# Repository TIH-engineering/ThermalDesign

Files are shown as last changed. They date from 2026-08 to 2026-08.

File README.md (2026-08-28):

# ThermalDesign






## 🔌 Leiterplattenbeschreibung

Die Leiterplatte **ThermalDesign** dient zur praktischen Untersuchung des **thermischen Verhaltens elektronischer Bauteile**. Als Versuchsobjekt werden mehrere LM317-Linearregler unter unterschiedlichen thermischen Bedingungen und bei verschiedenen Belastungen betrieben.

Die Leiterplatte enthält vier vergleichbare Spannungsreglerstufen mit einer Ausgangsspannung von etwa **2,5 V**. Die Regler unterscheiden sich insbesondere hinsichtlich ihrer thermischen Anbindung:

- **LM317 im SOT-223-Gehäuse**
- **LM317 im TO-220-Gehäuse**
- **LM317 im SOT-223-Gehäuse mit zusätzlicher Kupferfläche zur Wärmeabfuhr**
- **LM317 im TO-220-Gehäuse mit Kühlkörper**

Über verschiedene Lastwiderstände können unterschiedliche Lastfälle eingestellt werden. Vorgesehen sind Untersuchungen bei ungefähr:

- **100 mA**
- **250 mA**
- **500 mA**
- **1 A** als gepulste Last

Die 1-A-Last wird über einen MOSFET geschaltet und kann mit einem externen PWM-Signal angesteuert werden. Dadurch lassen sich neben stationären Temperaturzuständen auch **dynamische Erwärmungs- und Abkühlvorgänge** untersuchen.

Mit der Leiterplatte können unter anderem der Zusammenhang zwischen **Verlustleistung, Bauteiltemperatur, thermischem Widerstand, Gehäusebauform, Kupferfläche und Kühlkörper** experimentell untersucht werden. Die Messergebnisse können mit theoretischen Berechnungen oder thermischen Ersatzschaltbildern verglichen werden.

> **Einsatzgebiet:** Laborübungen und Unterricht zu thermischem Design, Verlustleistung, Wärmewiderständen, Linearreglern und Kühlung elektronischer Bauteile

---

## 📥 Downloads

| Datei | Beschreibung |
|---|---|
| 📄 [Schaltplan (PDF)](../../releases/latest/download/schematic.pdf) | Schaltplan der Leiterplatte |
| 🖨️ [Leiterplatte (PDF)](../../releases/latest/download/pcb.pdf) | Leiterplattenansicht als PDF |
| 🔩 [Bohrplan (PDF)](../../releases/latest/download/drill.pdf) | Bohrdaten / Bohrplan |
| 📋 [Stückliste (Excel)](../../releases/latest/download/bom.xlsx) | Bill of Materials |
| 🌐 [Interactive BOM](../../releases/latest/download/ibom.html) | Interaktive Bestückungsansicht |
| 📦 [Fertigungsdaten](../../releases/latest/download/kicad.zip) | Gerber- und Bohrdaten |
| 🧊 [STEP-Modell](../../releases/latest/download/pcb.step) | 3D-Modell der Leiterplatte |

Die Dateien werden automatisch durch den Release-Workflow erzeugt.

---

## 🖥️ Leiterplatte

### Vorschau

| Oberseite | Unterseite |
|:---:|:---:|
| PCB Top | PCB Bottom |

### Oberseite

PCB Top

### Unterseite

PCB Bottom

---

## ℹ️ Projektinformationen

| Eigenschaft | Wert |
|---|---|
| **Projekt** | ThermalDesign |
| **Software** | KiCad 10 |
| **Repository** | TIH-engineering/ThermalDesign |
| **Autor** | [TIH] |
| **Lizenz** | CC BY-NC-SA 4.0 |

---

## 🗂️ Repository-Struktur

```text
.
├── .github/
│   └── workflows/       # GitHub Actions
├── .kibot/              # KiBot-Konfiguration
├── pcb/
│   ├── lib/             # Projektspezifische Bibliotheken
│   └── ...              # KiCad-Projektdateien
├── .gitignore
├── LICENSE
└── README.md

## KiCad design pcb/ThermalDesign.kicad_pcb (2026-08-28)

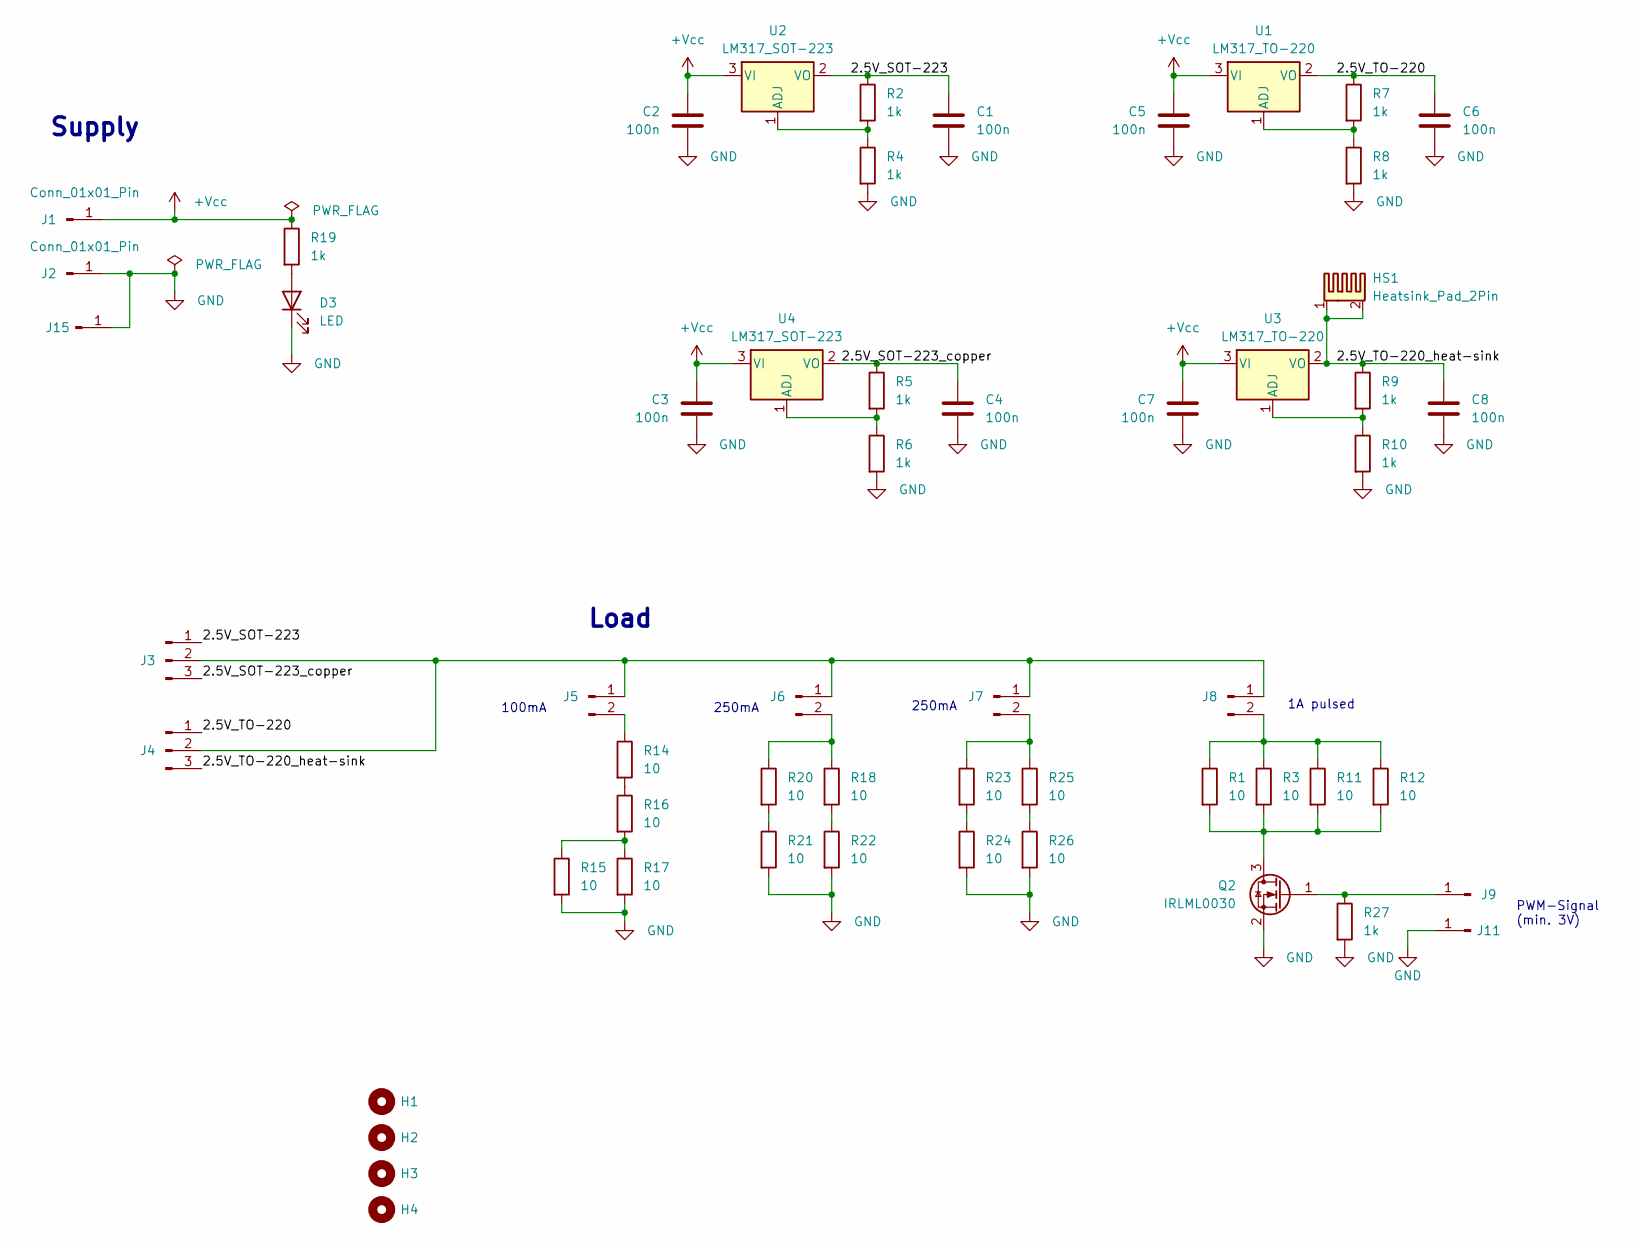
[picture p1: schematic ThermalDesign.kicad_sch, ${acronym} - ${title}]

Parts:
C1, C2, C3, C4, C5, C6, C7, C8: 100n; C_1206_3216Metric
D3: LED; LED_1206_3216Metric
H1, H2, H3, H4: MountingHole; MountingHole_3.2mm_M3
HS1: Heatsink_Pad_2Pin; Heatsink_Fischer_SK129-STS_42x25mm_2xDrill2.5mm
J1, J2, J9, J11, J15: Conn_01x01_Pin; PinHeader_1x01_P2.54mm_Vertical
J3, J4: Conn_01x03_Pin; PinHeader_1x03_P2.54mm_Vertical
J5, J6, J7, J8: Conn_01x02_Pin; PinHeader_1x02_P2.54mm_Vertical
Q2: IRLML0030; SOT-23
R1, R3, R11, R12, R14, R15, R16, R17, R18, R20, R21, R22, R23, R24, R25, R26: 10; R_1206_3216Metric
R2, R4, R5, R6, R7, R8, R9, R10, R19, R27: 1k; R_1206_3216Metric
U1, U3: LM317_TO-220; TO-220-3_Vertical
U2, U4: LM317_SOT-223; SOT-223-3_TabPin2

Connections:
+Vcc: C2.1, C3.1, C5.1, C7.1, J1.1 (Pin_1_1), R19.1, U1.3 (VI), U2.3 (VI), U3.3 (VI), U4.3 (VI)
/2.5V_SOT-223: C1.1, J3.1, R2.1, U2.2 (VO)
/2.5V_SOT-223_copper: C4.1, J3.3, R5.1, U4.2 (VO)
/2.5V_TO-220: C6.1, J4.1, R7.1, U1.2 (VO)
/2.5V_TO-220_heat-sink: C8.1, HS1.1, HS1.2, J4.3, R9.1, U3.2 (VO)
GND: C1.2, C2.2, C3.2, C4.2, C5.2, C6.2, C7.2, C8.2, D3.1 (K), J2.1 (Pin_1_1), J11.1 (Pin_1_1), J15.1 (Pin_1_1), Q2.2 (S), R4.2, R6.2, R8.2, R10.2, R15.2, R17.2, R21.2, R22.2, R24.2, R26.2, R27.2
unnamed: D3.2 (A), R19.2
unnamed: J3.2, J4.2, J5.1, J6.1, J7.1, J8.1
unnamed: J5.2, R14.1
unnamed: J6.2, R18.1, R20.1
unnamed: J7.2, R23.1, R25.1
unnamed: J8.2, R1.1, R3.1, R11.1, R12.1
unnamed: J9.1 (Pin_1_1), Q2.1 (G), R27.1
unnamed: Q2.3 (D), R1.2, R3.2, R11.2, R12.2
unnamed: R14.2, R16.1
unnamed: R15.1, R16.2, R17.1
unnamed: R18.2, R22.1
unnamed: R20.2, R21.1
unnamed: R23.2, R24.1
unnamed: R25.2, R26.1
unnamed: R7.2, R8.1, U1.1 (ADJ)
unnamed: R2.2, R4.1, U2.1 (ADJ)
unnamed: R9.2, R10.1, U3.1 (ADJ)
unnamed: R5.2, R6.1, U4.1 (ADJ)

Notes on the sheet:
250mA
PWM-Signal (min. 3V)
Supply
100mA
Load
1A pulsed

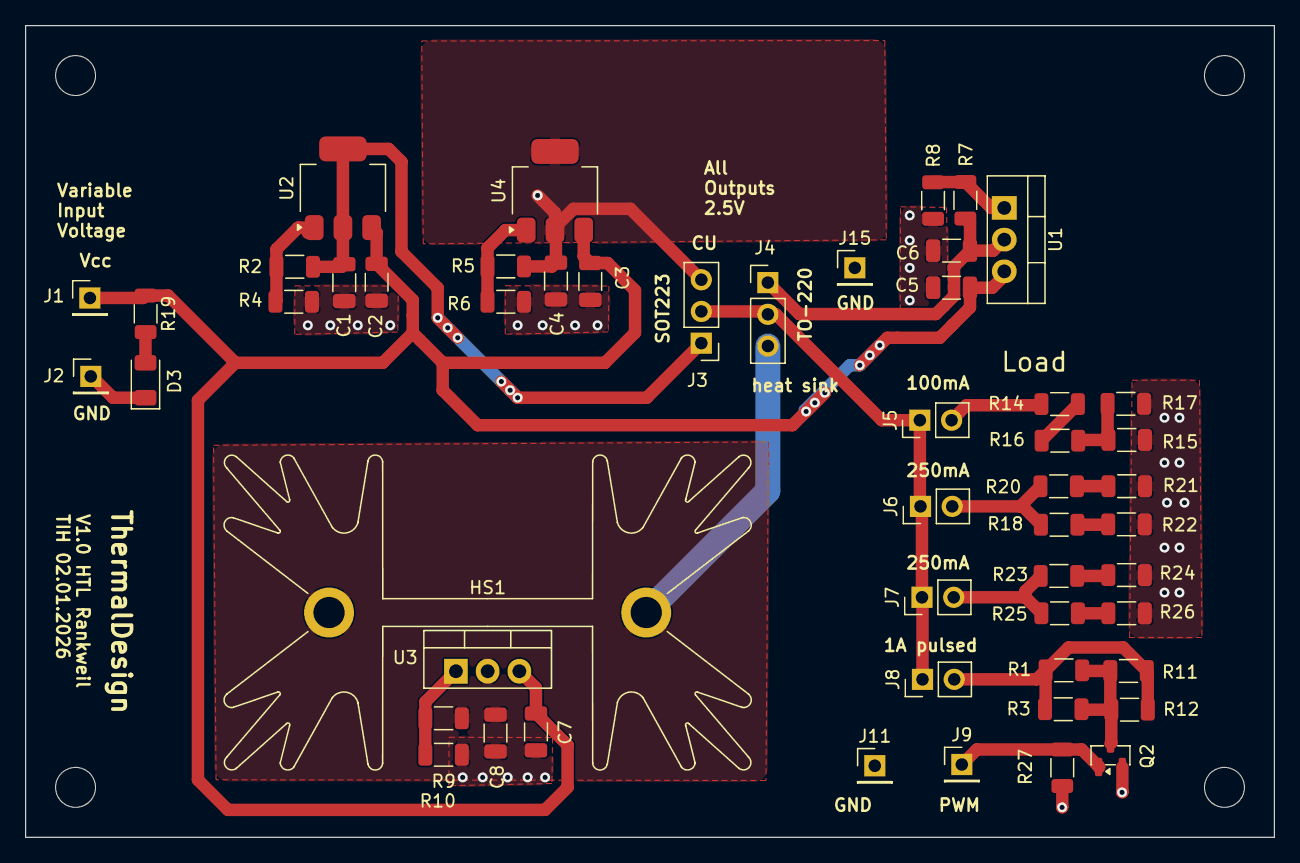
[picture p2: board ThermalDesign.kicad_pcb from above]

Board: 2 copper layers, 100.0 x 65.0 mm, 56 parts (0 on the bottom side), 24 nets.

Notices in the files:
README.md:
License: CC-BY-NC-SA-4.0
